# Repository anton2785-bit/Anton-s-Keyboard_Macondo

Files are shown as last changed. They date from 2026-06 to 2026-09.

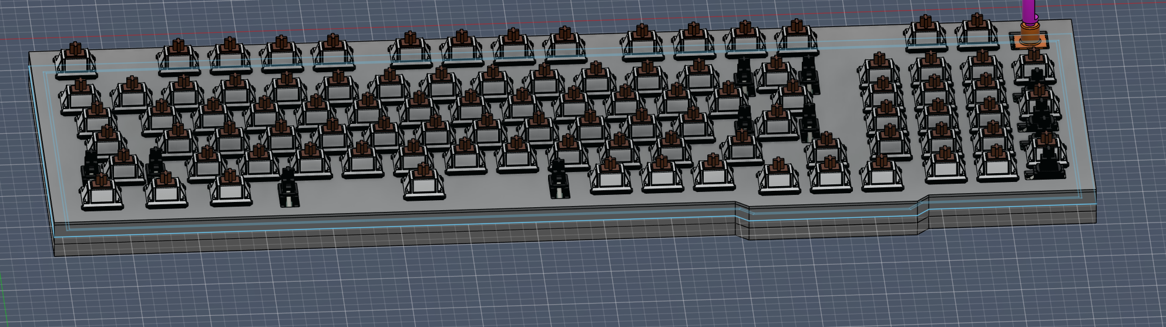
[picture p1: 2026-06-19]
Images/Assembly.png

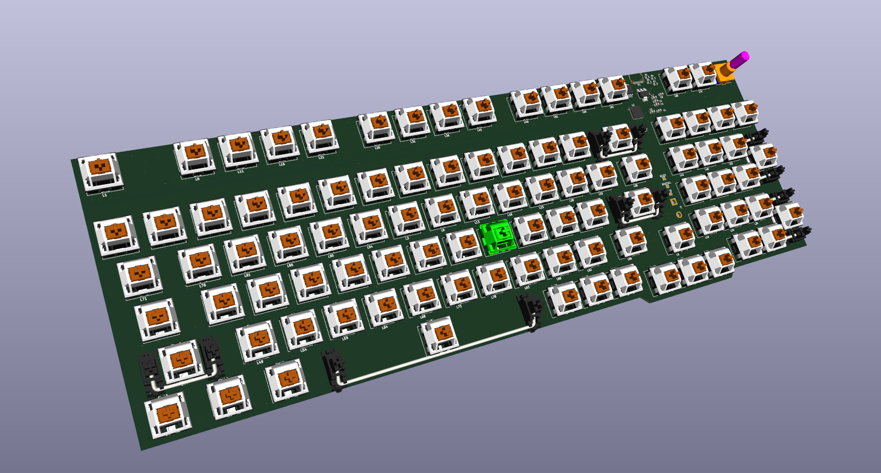
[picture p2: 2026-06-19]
Images/3d model PCB.png

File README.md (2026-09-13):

# Anton's kayboard
--- 
### What is this project
* This is a keyboar that uses thr 1800 compact layout (an almost 100% keyboard without most of the keys between the enter and the numpad). This keyboard uses an rp2040 chip for its 30 gpio pins that make the making of the keyboard PCB layout easier. Bellow every hotswapable key there is a LED that is wired to every other one and can be controlled with code. 
3d model PCB

--- 
### Why I made this project
* I made this keyboard because I wanted to try a bigger more complx PCB that I would be able to use everyday.
* Also I wanted to update my keyboard with one that I made.

--- 
### Images
* The schematic for the PCB
schematic
* The schematic for the hierarchal sheets and what is in it
Shematic herarcial sheets
* The layout and the PCB
PCB
* The 3D model of the case and assembly of the keyboard
* 
Assembly

--- 
### BOM
| Component | Purpose | Qty | Total Cost (USD) | Distributor |
|---|---|:---:|:---:|---|
| Gateron Stabilizer | Prevents larger switches from wobbling | 1 | $9.45 | Gateron |
| Decoupling Capacitors (100nF) | Reduce electrical noise before the LEDs | 2 | $3.20 | AliExpress |
| LEDs (SK6812 Mini-E) | RGB underglow beneath the switches | 1 | $3.56 | AliExpress |
| Keycaps | Keycaps | 1 | $15.78 | AliExpress |
| Rotary Encoder (EC11E) | Rotary knob for volume / scroll | 1 | $2.78 | AliExpress |
| Diodes (1N4148W) | Prevent signal backflow in the matrix | 2 | $3.60 | AliExpress |
| Resistors (4.7 kΩ and 350 Ω) | Current limiting for LEDs and I²C pull-ups | 1 | $4.10 | AliExpress |
| Foam | Sound dampening layer under the PCB | 1 | $7.77 | AliExpress |
| Coiled Cable | Connecting cable for the keyboard | 1 | $5.55 | AliExpress |
| PCB | Main circuit board | 1 | $59.00 | JLCPCB |
| Microcontroller (YD-RP2040) | Runs the keyboard firmware (KMK / CircuitPython) | 1 | $2.94 | AliExpress |
| Gateron Switches | The switches you type on | 1 | $29.00 | Gateron |
| Hotswap Sockets | Allow switches to be swapped without soldering | 1 | $6.68 | Gateron |
| **Total** | | | **$153.51** | |

--- 
### Assembly
* First you need to soulder the smaller components (the diodes and capacitors) just for your sanity because later it will get harder.
* The secpnd smallest thingyou need to soulder many of are the LEDs.
* After that you are free to soulder the hotswap sockets.
* The chip can be souldered at any time.
* The keys and kaycaps must be placed after the PCB is put into the case and secured with the top case.

--- 
### Known problems
* The code is almost entirely made by claude because I dont have the chip with me and I cant write the code.

--- 
### Credits
* Designed and built by *(Anton/ Anton-2785-bit)
* Inspired by open‑source mechanical keyboard and hackpad communities (https://forge.hackclub.com/).

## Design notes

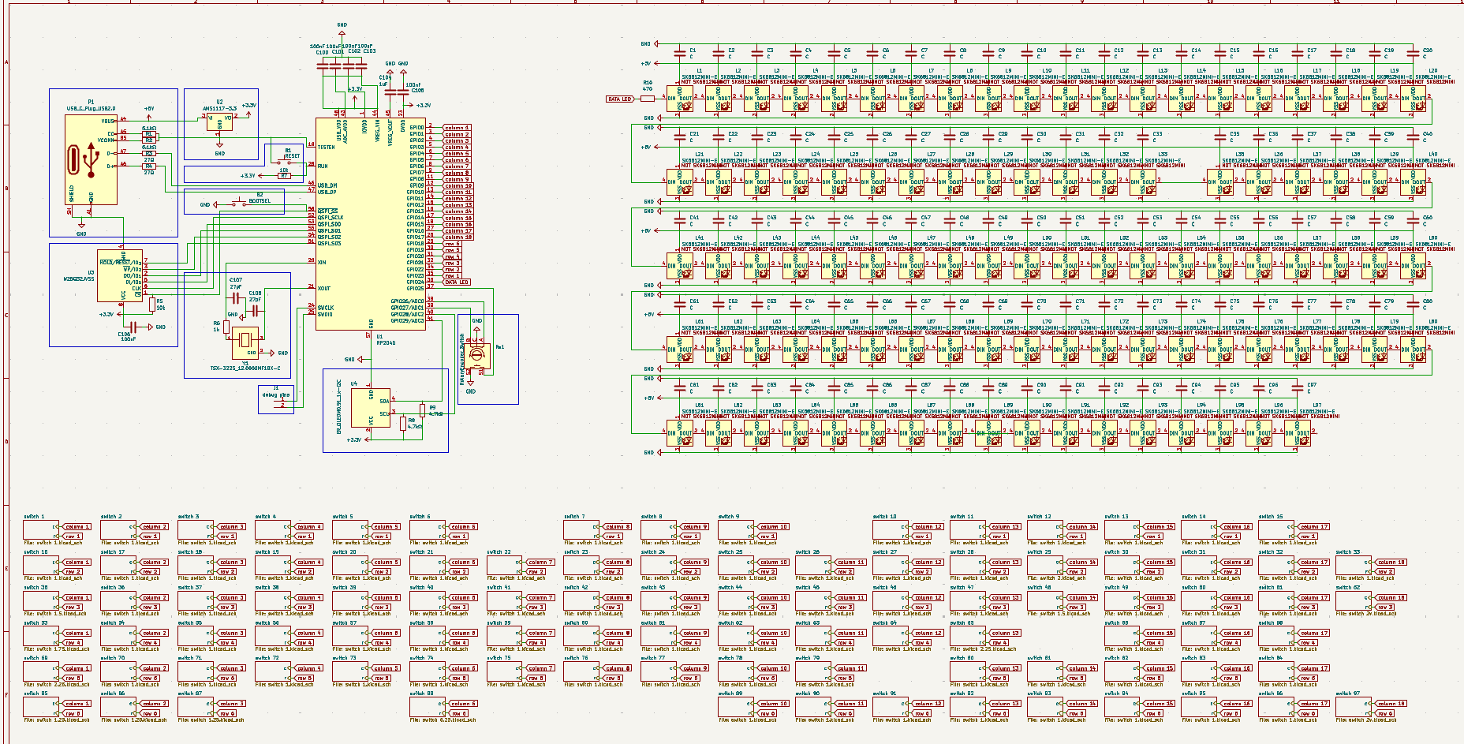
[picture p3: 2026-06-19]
Images/schematic.png

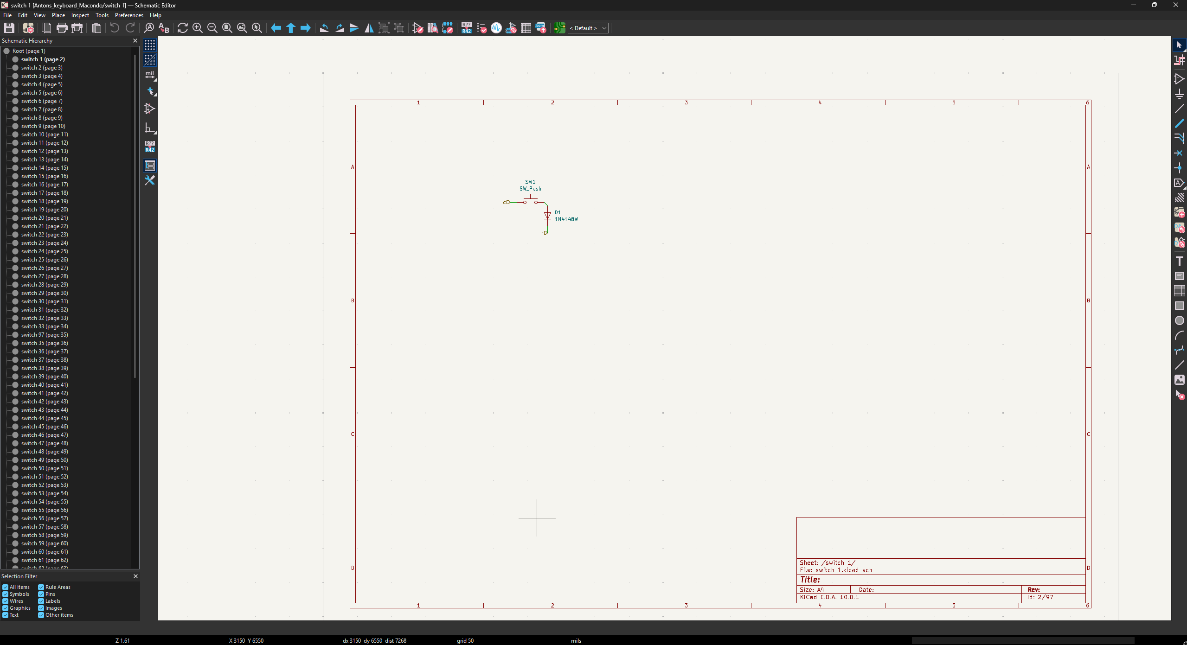
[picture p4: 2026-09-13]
Images/Shematic herarcial sheets.png

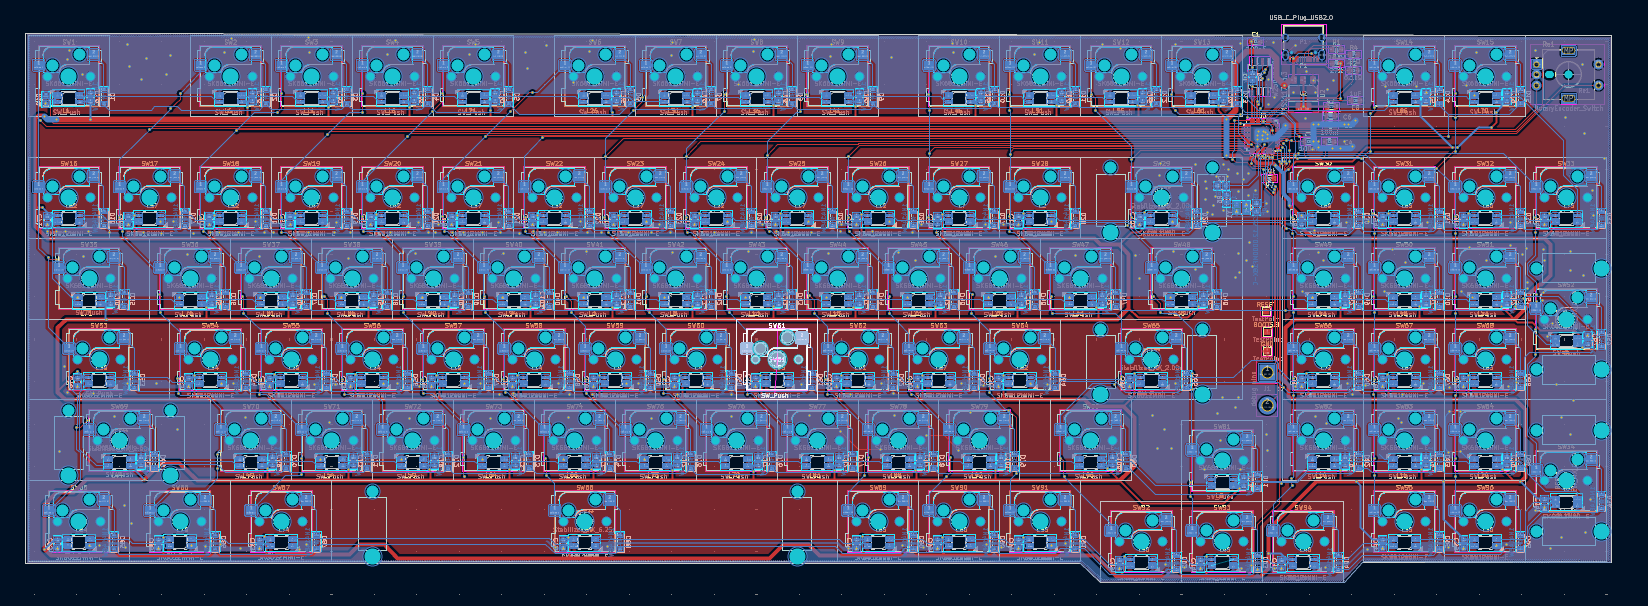
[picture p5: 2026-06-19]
Images/PCB.png

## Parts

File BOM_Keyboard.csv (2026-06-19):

Name | Purpose | Quantity | Total Cost (USD) | Link | Distributor
Gateroon stabilizer | makes the bigger switches not wable | 1 | 9.45 |  | gateron
decoupling capacitors ( 100nF ) | The capacitors are for lowering the electrical noise before the LEDs | 2 | 3.20 |  | Aliexpress
LEDs (SK 6812 mini E) | The LEDs bellow the switches | 1 | 3.56 |  | Aliexpress
keycaps | Keycaps | 1 | 15.78 |  | Aliexpress
Rotary encoder ( EC11E ) | A knob for twisting | 1 | 2.78 |  | Aliexpress
Diodes ( 1N4148W ) | Diodes, that stop form signal going back | 2 | 3.60 |  | Aliexpress
Resistors ( Pack of many ) | Resistors ( 4.7 kΩ and 350Ω) | 1 | 4.10 |  | Aliexpress
Foam | Used for making the keyboard sound betetr, its placed bellow the PCB | 1 | 7.77 |  | Aliexpress
Cable for keyboard | A cool coiled cable for the cable | 1 | 5.55 |  | Aliexpress
PCB | PCB | 1 | 59.00 |  | JLCPCB
Microcontroller (YD-RP 2040) | The microcontroller for the keyboard | 1 | 2.94 |  | Aliexpress
Gateroon switches | These are the switches that you type on | 1 | 29.00 |  | Gateron
Hotswap module | These modules allow for the easy change of the switches | 1 | 6.68 |  | Gateron

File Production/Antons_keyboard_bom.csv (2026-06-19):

Designator | Footprint | Quantity | Value | LCSC Part #
BOOTSEL, GND, RESET | TestPoint_Pad_1.5x1.5mm | 3 | TestPoint
C1, C4, C5, C6, C7, C9 | 0805 | 6 | 100nF
C10, C100, C101, C102, C103, C104, C105, C11, C12, C13, C14, C15, C16, C17, C18, C19, C20, C21, C22, C23, C24, C25, C26, C27, C28, C29, C30, C31, C32, C33, C34, C35, C36, C37, C38, C39, C40, C41, C42, C43, C44, C45, C46, C47, C48, C49, C50, C51, C52, C53, C54, C55, C56, C57, C58, C59, C60, C61, C62, C63, C64, C65, C66, C67, C68, C69, C70, C71, C72, C73, C74, C75, C76, C77, C78, C79, C80, C81, C82, C83, C84, C85, C86, C87, C88, C89, C90, C91, C92, C93, C94, C95, C96, C97, C98, C99 | 0805 | 96 | C
C2, C3 | 0805 | 2 | 27pF
C8 | 0805 | 1 | 1uF
D1, D10, D11, D12, D13, D14, D15, D16, D17, D18, D19, D2, D20, D21, D22, D23, D24, D25, D26, D27, D28, D29, D3, D30, D31, D32, D33, D34, D35, D36, D37, D38, D39, D4, D40, D41, D42, D43, D44, D45, D46, D47, D48, D49, D5, D50, D51, D52, D53, D54, D55, D56, D57, D58, D59, D6, D60, D61, D62, D63, D64, D65, D66, D67, D68, D69, D7, D70, D71, D72, D73, D74, D75, D76, D77, D78, D79, D8, D80, D81, D82, D83, D84, D85, D86, D87, D88, D89, D9, D90, D91, D92, D93, D94, D95, D96 | D_SOD-123 | 96 | 1N4148W
J1 | SolderWire-2sqmm_1x02_P7.8mm_D2mm_OD3.9mm | 1 | debug pins
L1, L10, L11, L12, L13, L14, L15, L16, L17, L18, L19, L2, L20, L21, L22, L23, L24, L25, L26, L27, L28, L29, L3, L30, L31, L32, L33, L34, L35, L36, L37, L38, L39, L4, L40, L41, L42, L43, L44, L45, L46, L47, L48, L49, L5, L50, L51, L52, L53, L54, L55, L56, L57, L58, L59, L6, L60, L61, L62, L63, L64, L65, L66, L67, L68, L69, L7, L70, L71, L72, L73, L74, L75, L76, L77, L78, L79, L8, L80, L81, L82, L83, L84, L85, L86, L87, L88, L89, L9, L90, L91, L92, L93, L94, L95, L96 | SK6812MINI-E_fixed | 96 | SK6812MINI-E
P1 | USB_C_Receptacle_HRO_TYPE-C-31-M-12 | 1 | USB_C_Plug_USB2.0
R1, R2 | 0805 | 2 | 5.1kΩ
R10 | 0805 | 1 | 470
R3, R4 | 0805 | 2 | 27Ω
R5, R7 | 0805 | 2 | 10k
R6 | 0805 | 1 | 1k
RE1 | RotaryEncoder_Alps_EC11E-Switch_Vertical_H20mm_MountingHoles | 1 | RotaryEncoder_Switch
SW1, SW10, SW11, SW12, SW13, SW14, SW15, SW16, SW17, SW18, SW19, SW2, SW20, SW21, SW22, SW23, SW24, SW25, SW26, SW27, SW28, SW3, SW30, SW31, SW32, SW33, SW36, SW37, SW38, SW39, SW4, SW40, SW41, SW42, SW43, SW44, SW45, SW46, SW47, SW49, SW5, SW50, SW51, SW54, SW55, SW56, SW57, SW58, SW59, SW6, SW60, SW61, SW62, SW63, SW64, SW66, SW67, SW68, SW7, SW70, SW71, SW72, SW73, SW74, SW75, SW76, SW77, SW78, SW79, SW8, SW80, SW81, SW82, SW83, SW84, SW89, SW9, SW90, SW91, SW92, SW93, SW94, SW95, SW96 | Hotswap_MX_1.00u | 84 | SW_Push
SW29 | Hotswap_MX_2.00u | 1 | SW_Push
SW34, SW52 | Hotswap_MX_2.00u_90deg | 2 | SW_Push
SW35, SW48 | Hotswap_MX_1.50u | 2 | SW_Push
SW53 | Hotswap_MX_1.75u | 1 | SW_Push
SW65, SW69 | Hotswap_MX_2.25u | 2 | SW_Push
SW85, SW86, SW87 | Hotswap_MX_1.25u | 3 | SW_Push
SW88 | Hotswap_MX_6.25u | 1 | SW_Push
U1 | SOIC-8_5.3x5.3mm_P1.27mm | 1 | W25Q32JVSS
U2 | SOT-223-3_TabPin2 | 1 | AMS1117-3.3
U3 | QFN-56-1EP_7x7mm_P0.4mm_EP3.2x3.2mm | 1 | RP2040
Y1 | XTAL_TSX-3225_24.0000MF18X-C | 1 | TSX-3225_12.0000MF18X-C

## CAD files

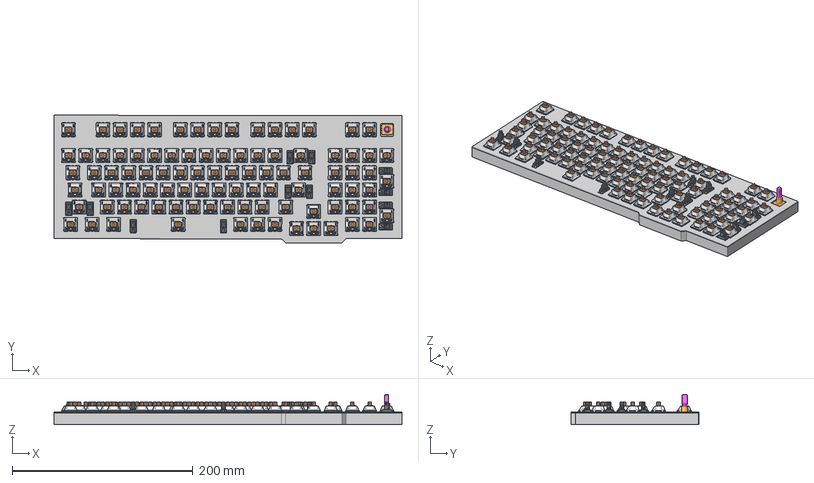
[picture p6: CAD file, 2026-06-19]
CAD/Antons_keyboard.step
385.3 x 141.4 x 33.5 mm
Hotswap_MX x 96
MX_PCB x 96
Stabilizer_MX_2.00u x 10
SK6812-E--3DModel-STEP-418109 x 96
ec11e18244a5
R_0805_2012Metric x 8
C_0805_2012Metric x 105
Stabilizer_MX_6.25u
SOT-223
SOIC-8_5.3x5.3mm_P1.27mm
QFN-56-1EP_7x7mm_P0.4mm_EP3.2x3.2mm
D_SOD-123 x 96
Antons_keyboard_Macondo_PCB

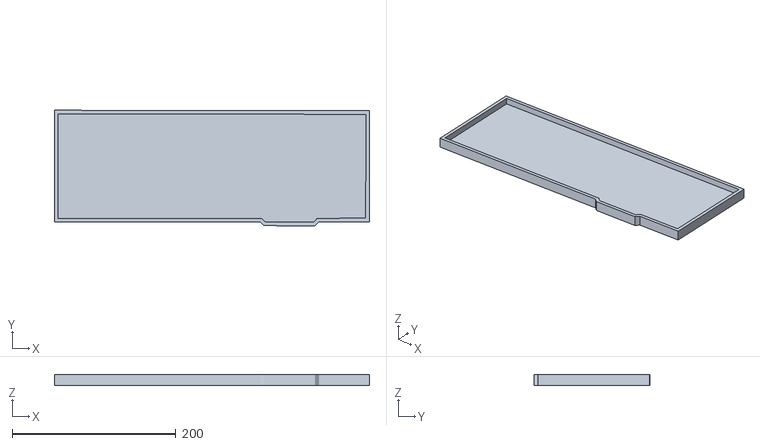
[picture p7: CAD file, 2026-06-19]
Production/Bottom case keyboard.stl
385.3 x 141.4 x 13.0

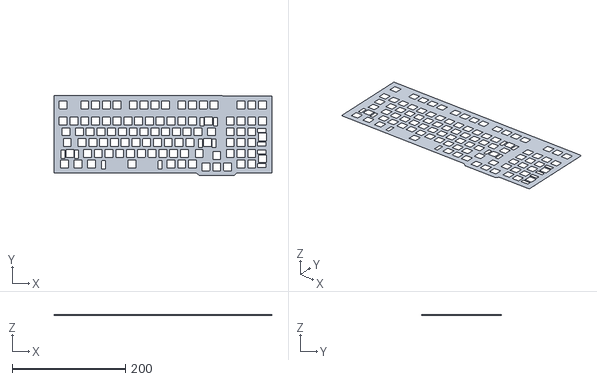
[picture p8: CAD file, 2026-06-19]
Production/top plate keyboard.stl
385.3 x 141.4 x 1.00

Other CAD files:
CAD/Antons_keyboard.f3d

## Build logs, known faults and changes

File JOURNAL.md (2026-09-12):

---
title: "Keyboard"
author: "antondimitrov2785"
description: "Its a keyboard using the 1800 compact layout"
created_at: "2026-09-11"
---

# 2026-09-11: Making the case

**Total time spent: 1.0 hours**

I didnt make it complicated. tye top plate will just slide in befort any of the keys are placed and then they will secure the plate down 

# 2026-09-11: Adding GND and 3D models

**Total time spent: 2.5 hours**

In this time I had to add like 150 vias all around the PCB because I had screwed up with one of the steps that were made to make the process easier. Other than that it is all good. 
After that I had to find a way to add the 3D models. I had forgotten how t o do that but I managed to do it and now everything but the keycaps is there (I think there is no need of them on the switches and they will make the process a bt harder).

# 2026-09-11: conected the LEDs to the 5v rails

**Total time spent: 1.5 hours**

It wasnt ahrd. My the only thing that I didnt account for was the many vias that I needed to place. I had specificly wanted to make it easy to wire then the GND, but it looks like it wouldnt happen


# 2026-09-11: Adding stabilizers and 5v rail

**Total time spent: 2.5 hours**

I needed the 5v rail for all of the LEDs. That is why it is much ticker than the other lines. The stabilizers were straight forward. 


# 2026-09-11: Connecting some resistors and lines

**Total time spent: 0.5 hours**

I had forgotten to add some of the resistors that are connected to the USB and chip. I moved the crystal which I will wire some other day. 


# 2026-09-11: making the columns bus

**Total time spent: 1.5 hours**

I needed to connect every column to the chip. And I didnt want to make it too hard later on with the GND layers. 


# 2026-09-11: Making the chip assembly

**Total time spent: 1.0 hours**

I needed to add the chip modules and all of the caps and everything that is related to it. Now I haave to connect every column and row.


# 2026-09-11: Adding LED and caps

**Total time spent: 3.0 hours**

I needed to add every led and capacitor. FOr each other row I had to flip the LED and the cap so that it would be easier to wire it later. that alone will save me 2 hours in the future. 

# 2026-09-11: Arranging the Switches

**Total time spent: 4.0 hours**

I added the footrpints and I needed to start to arrangе all of the switches and LEDs. 

After the hours I spent arranging the switches and diodes I have it for now. I spent more time than I needed because I wanted all of them to be at the same place relative to the centre of the switch to make it easier to wire and soulder later.  


# 2026-09-11: Assigning footprints

**Total time spent: 1.0 hours**

I wanted to handsoulder everything do I made the caps size 0805 to make it easier and the diodes are sot-123. The switches will be on hotswap module. 


# 2026-09-11: Adding LEDs and caps

**Total time spent: 1.0 hours**

Almost each LED needs an capacitor to smooth out the current for each LED. This is required because there are 96 LED on one single 5v line. 


# 2026-09-11: Adding the switches

**Total time spent: 2.0 hours**

I decided to place each key into its own sheet so it would be easier to assign the footprints later. The last thing I need to add to the schematic is the LED with their caps and then Im going to start on the layout and PCB. 


# 2026-09-11: The chip side is done

**Total time spent: 2.0 hours**

This part wasnt the easiest nor of the hardest. I just had to search what pin to connect where. And now I have to make the LEDs and the switches. 


# 2026-09-11: Getting schematic symbols

**Total time spent: 1.0 hours**

This is the symbols that will be for the chip and the things around it. The keys and diodes will follow up next. 


# 2026-09-11: Chip

**Total time spent: 1.0 hours**

For this keyboard I have decided to not use a devboard. I will integrate the chip with all of the components it needs into the keyboard to make the keyboard a bit smaller and easier to work with. 

# 2026-09-11: Layout

**Total time spent: 1.5 hours**

I will use a 1800 compact layout. I have chosen this one because I dont need the keys that are cut short from the full sized keyboard and if I happen to need them they will be just on a lower layer of the symbols.

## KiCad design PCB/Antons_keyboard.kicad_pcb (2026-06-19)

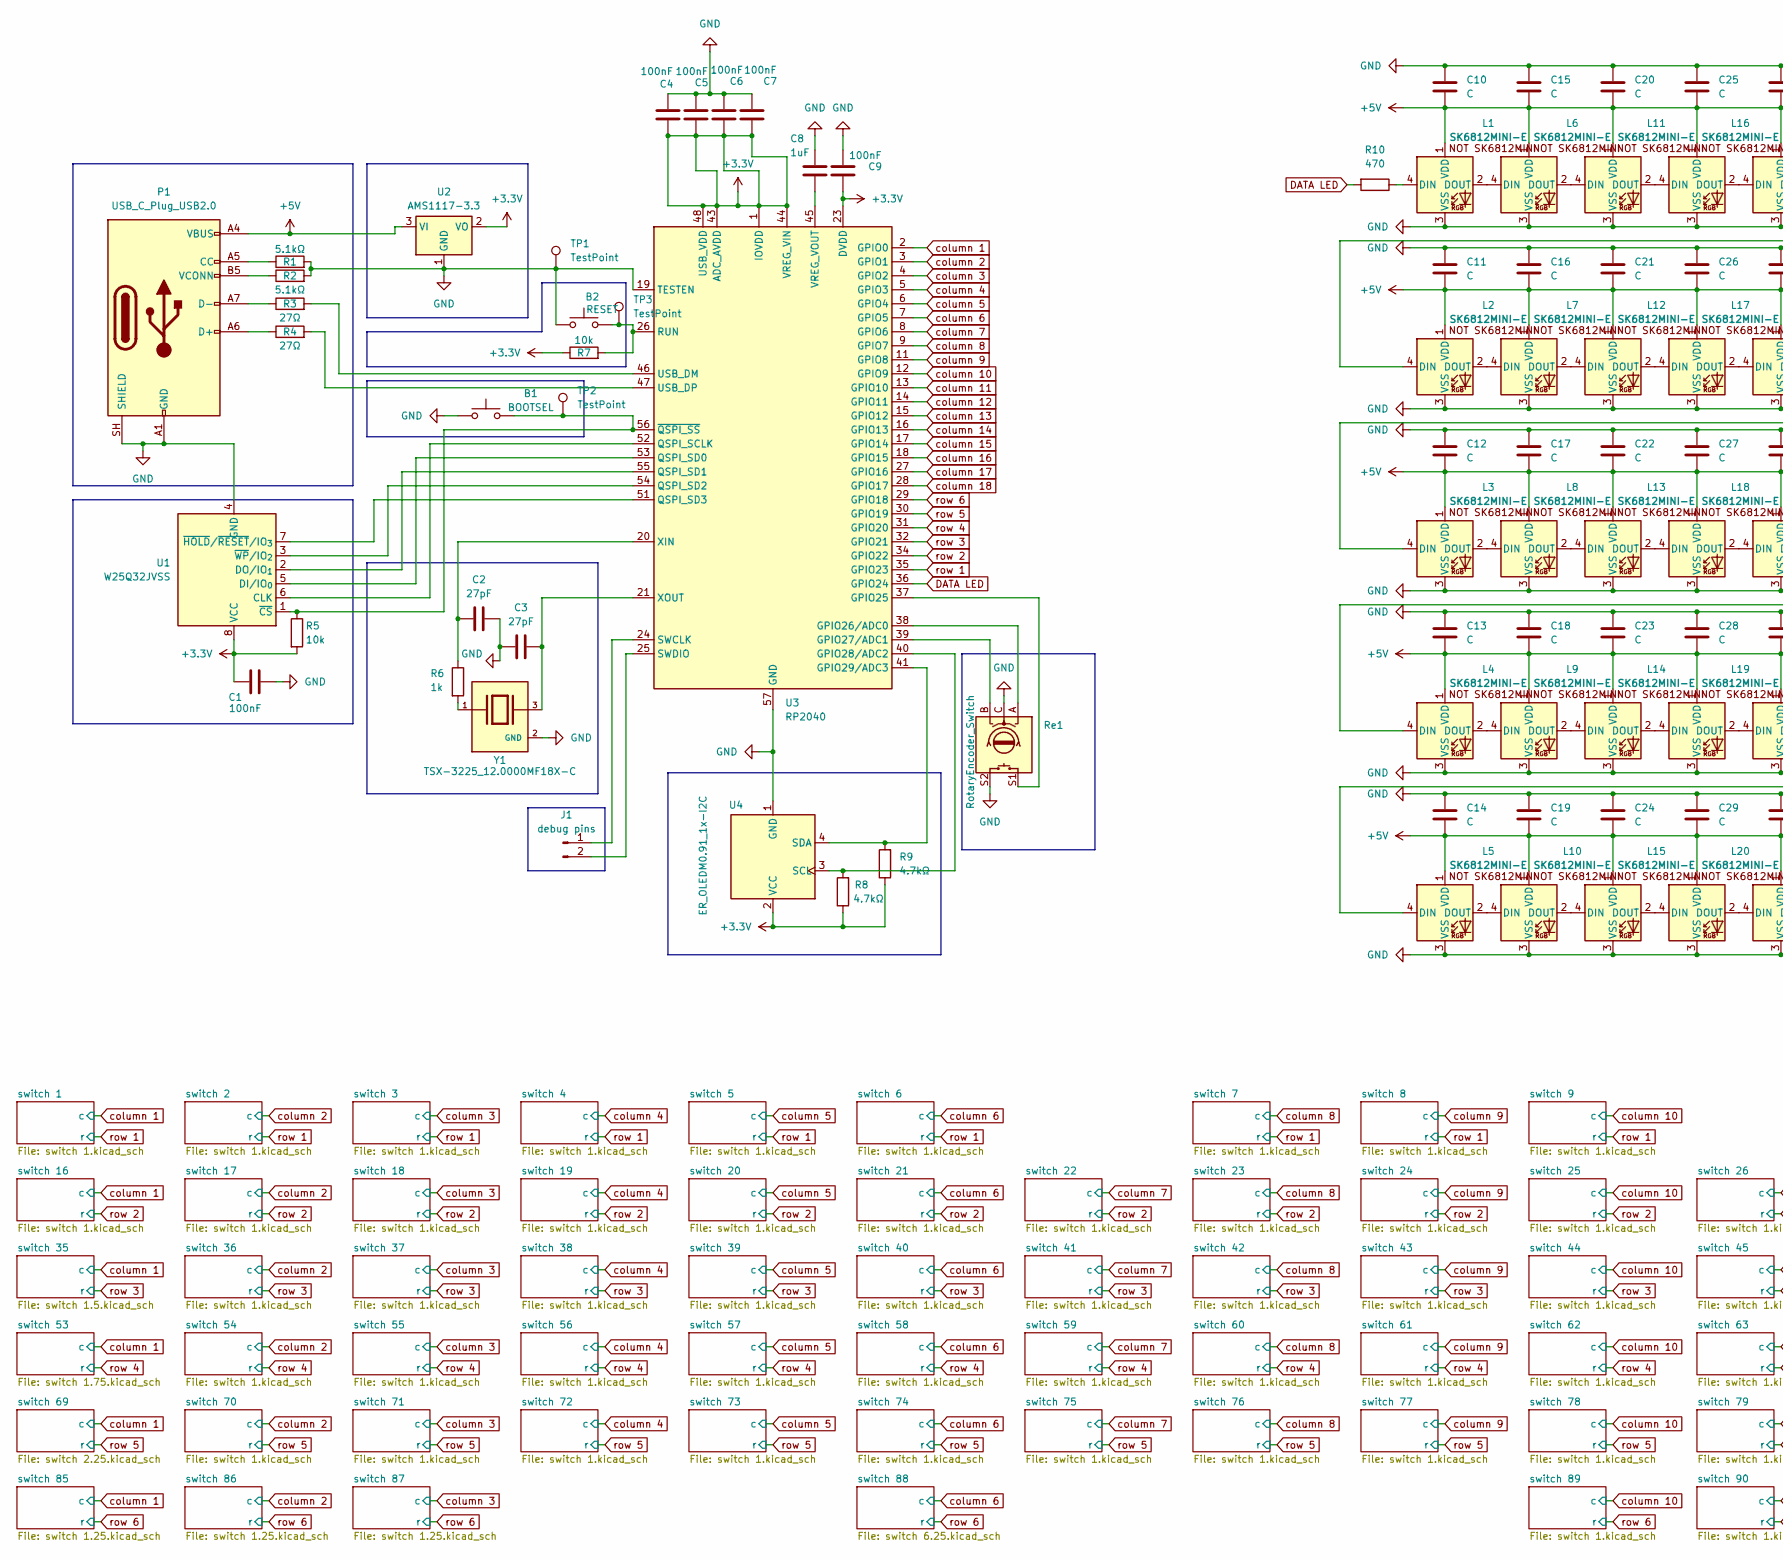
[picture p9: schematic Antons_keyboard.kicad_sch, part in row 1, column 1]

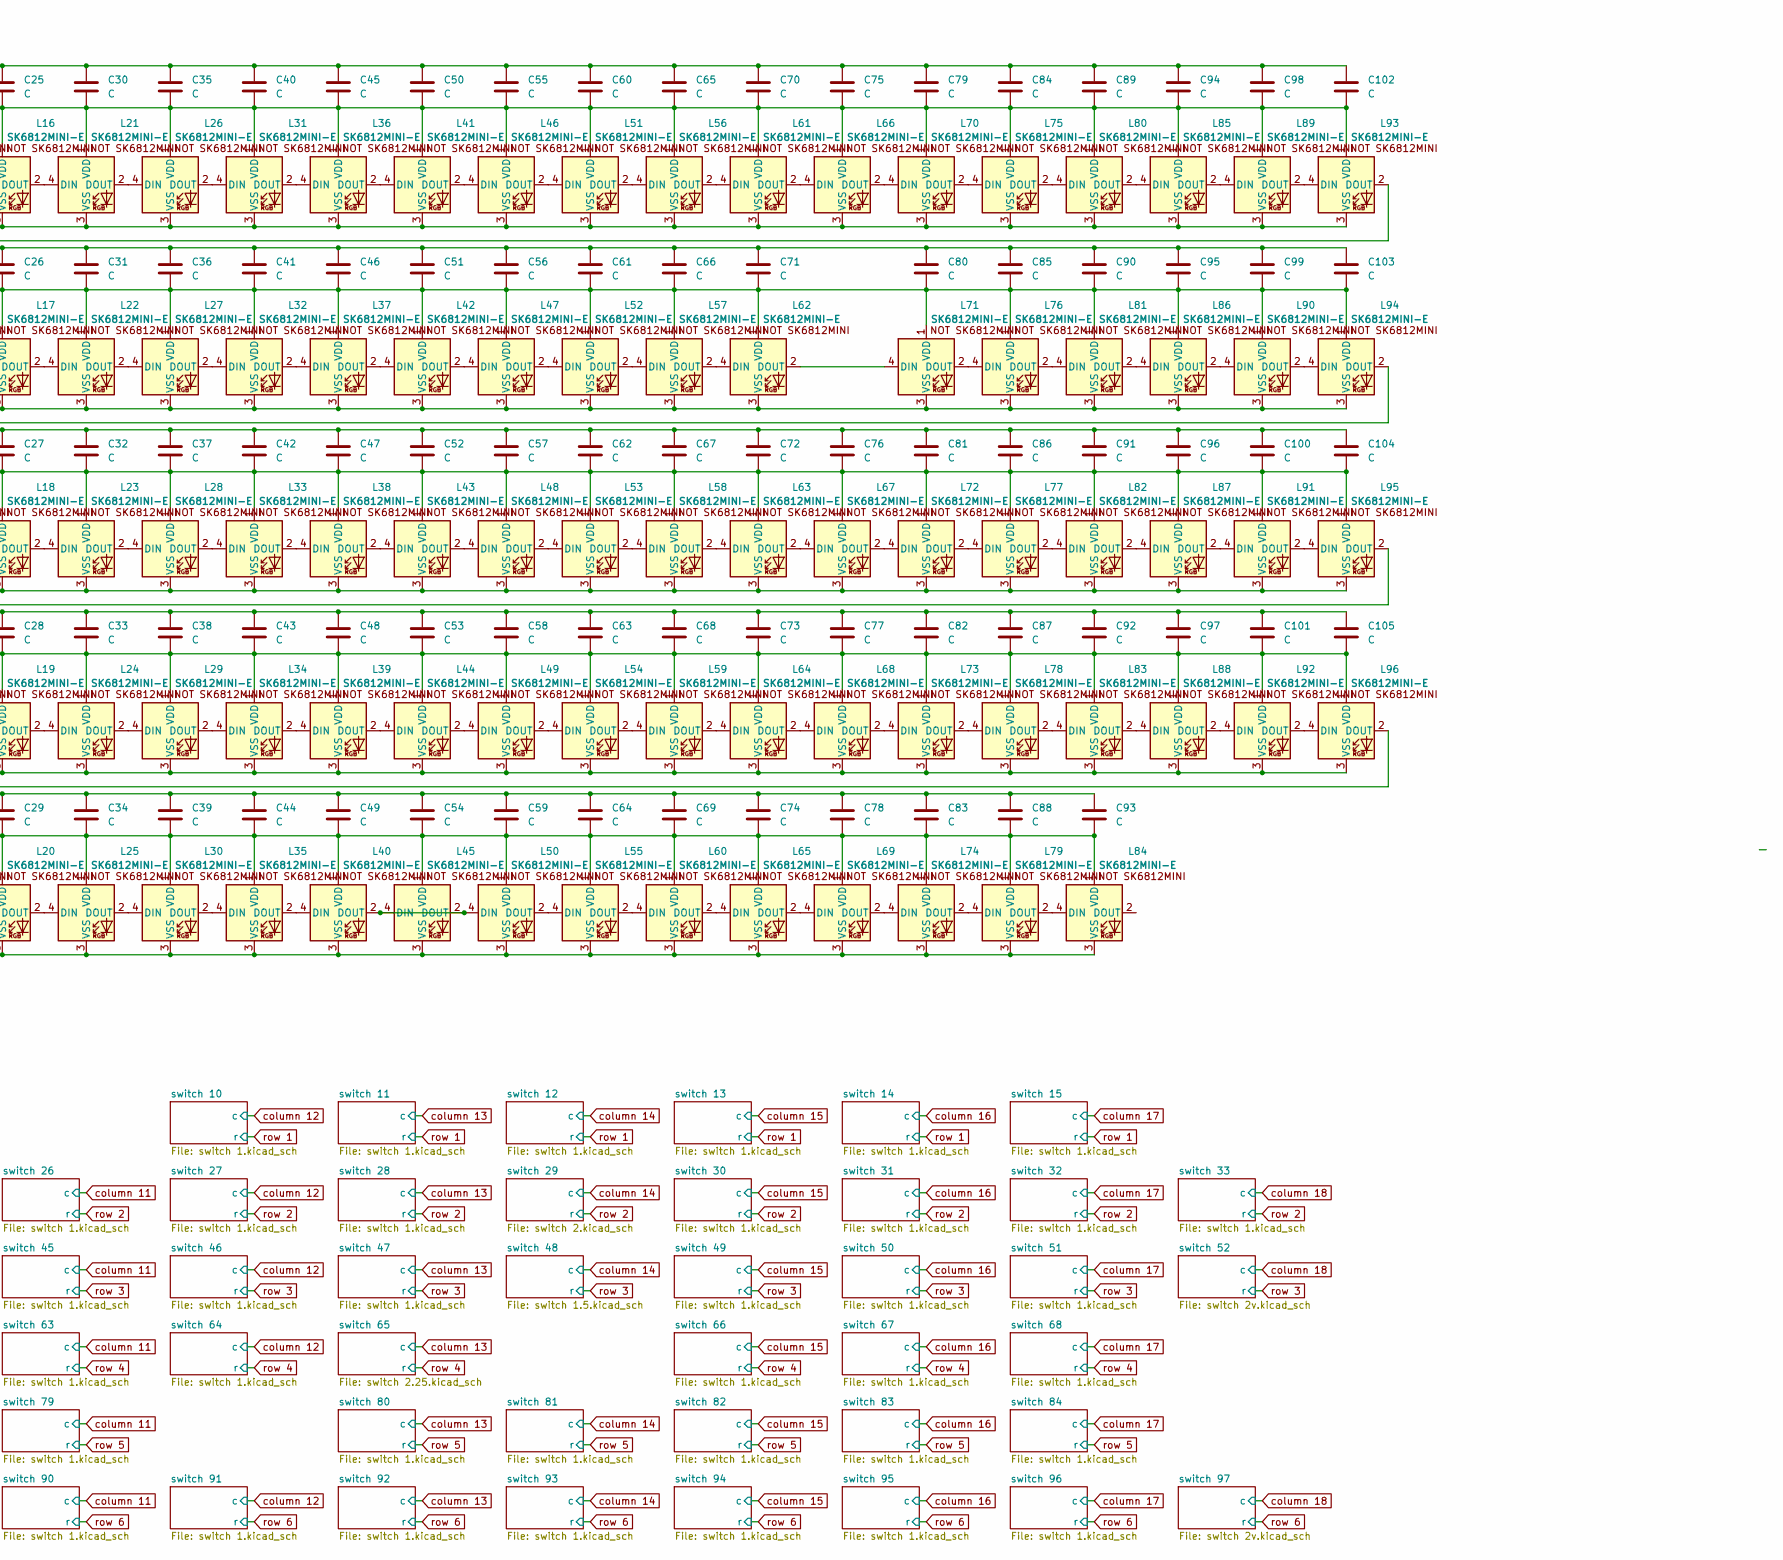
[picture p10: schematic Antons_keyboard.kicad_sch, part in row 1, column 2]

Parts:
B1: BOOTSEL
B2: RESET
C1, C4, C5, C6, C7, C9: 100nF; C_0805_2012Metric_Pad1.18x1.45mm_HandSolder
C2, C3: 27pF; C_0805_2012Metric_Pad1.18x1.45mm_HandSolder
C8: 1uF; C_0805_2012Metric_Pad1.18x1.45mm_HandSolder
C10, C11, C12, C13, C14, C15, C16, C17, C18, C19, C20, C21, C22, C23, C24, C25, C26, C27, C28, C29, C30, C31, C32, C33, C34, C35, C36, C37, C38, C39, C40, C41, C42, C43, C44, C45, C46, C47, C48, C49, C50, C51, C52, C53, C54, C55, C56, C57, C58, C59, C60, C61, C62, C63, C64, C65, C66, C67, C68, C69, C70, C71, C72, C73, C74, C75, C76, C77, C78, C79, C80, C81, C82, C83, C84, C85, C86, C87, C88, C89, C90, C91, C92, C93, C94, C95, C96, C97, C98, C99, C100, C101, C102, C103, C104, C105: C; C_0805_2012Metric_Pad1.18x1.45mm_HandSolder
J1: debug pins; SolderWire-2sqmm_1x02_P7.8mm_D2mm_OD3.9mm
L1, L2, L3, L4, L5, L6, L7, L8, L9, L10, L11, L12, L13, L14, L15, L16, L17, L18, L19, L20, L21, L22, L23, L24, L25, L26, L27, L28, L29, L30, L31, L32, L33, L34, L35, L36, L37, L38, L39, L40, L41, L42, L43, L44, L45, L46, L47, L48, L49, L50, L51, L52, L53, L54, L55, L56, L57, L58, L59, L60, L61, L62, L63, L64, L65, L66, L67, L68, L69, L70, L71, L72, L73, L74, L75, L76, L77, L78, L79, L80, L81, L82, L83, L84, L85, L86, L87, L88, L89, L90, L91, L92, L93, L94, L95, L96: SK6812MINI-E; SK6812MINI-E_fixed
P1: USB_C_Plug_USB2.0; USB_C_Receptacle_HRO_TYPE-C-31-M-12
R1, R2: 5.1kΩ; R_0805_2012Metric_Pad1.20x1.40mm_HandSolder
R3, R4: 27Ω; R_0805_2012Metric_Pad1.20x1.40mm_HandSolder
R5, R7: 10k; R_0805_2012Metric_Pad1.20x1.40mm_HandSolder
R6: 1k; R_0805_2012Metric_Pad1.20x1.40mm_HandSolder
R8, R9: 4.7kΩ; R_0805_2012Metric_Pad1.20x1.40mm_HandSolder
R10: 470; R_0805_2012Metric_Pad1.20x1.40mm_HandSolder
Re1: RotaryEncoder_Switch; RotaryEncoder_Alps_EC11E-Switch_Vertical_H20mm_MountingHoles
TP1, TP2, TP3: TestPoint; TestPoint_Pad_1.5x1.5mm
U1: W25Q32JVSS; SOIC-8_5.3x5.3mm_P1.27mm
U2: AMS1117-3.3; SOT-223-3_TabPin2
U3: RP2040; QFN-56-1EP_7x7mm_P0.4mm_EP3.2x3.2mm
U4: ER_OLEDM0.91_1x-I2C
Y1: TSX-3225_12.0000MF18X-C; XTAL_TSX-3225_24.0000MF18X-C; PARTREV N/A

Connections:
+3.3V: C1.1, C4.1, C5.1, C6.1, C7.1, C9.1, R5.2, R7.1, R8.1, R9.1, U1.8 (VCC), U2.2 (VO), U3.1 (IOVDD), U3.10 (IOVDD), U3.22 (IOVDD), U3.23 (DVDD), U3.33 (IOVDD), U3.42 (IOVDD), U3.43 (ADC_AVDD), U3.44 (VREG_VIN), U3.48 (USB_VDD), U3.49 (IOVDD), U3.50 (DVDD), U4.2 (VCC)
+5V: C10.1, C11.1, C12.1, C13.1, C14.1, C15.1, C16.1, C17.1, C18.1, C19.1, C20.1, C21.1, C22.1, C23.1, C24.1, C25.1, C26.1, C27.1, C28.1, C29.1, C30.1, C31.1, C32.1, C33.1, C34.1, C35.1, C36.1, C37.1, C38.1, C39.1, C40.1, C41.1, C42.1, C43.1, C44.1, C45.1, C46.1, C47.1, C48.1, C49.1, C50.1, C51.1, C52.1, C53.1, C54.1, C55.1, C56.1, C57.1, C58.1, C59.1, C60.1, C61.1, C62.1, C63.1, C64.1, C65.1, C66.1, C67.1, C68.1, C69.1, C70.1, C71.1, C72.1, C73.1, C74.1, C75.1, C76.1, C77.1, C78.1, C79.1, C80.1, C81.1, C82.1, C83.1, C84.1, C85.1, C86.1, C87.1, C88.1, C89.1, C90.1, C91.1, C92.1, C93.1, C94.1, C95.1, C96.1, C97.1, C98.1, C99.1, C100.1, C101.1, C102.1, C103.1, C104.1, C105.1, L1.1 (VDD), L2.1 (VDD), L3.1 (VDD), L4.1 (VDD), L5.1 (VDD), L6.1 (VDD), L7.1 (VDD), L8.1 (VDD), L9.1 (VDD), L10.1 (VDD), L11.1 (VDD), L12.1 (VDD), L13.1 (VDD), L14.1 (VDD), L15.1 (VDD), L16.1 (VDD), L17.1 (VDD), L18.1 (VDD), L19.1 (VDD), L20.1 (VDD), L21.1 (VDD), L22.1 (VDD), L23.1 (VDD), L24.1 (VDD), L25.1 (VDD), L26.1 (VDD), L27.1 (VDD), L28.1 (VDD), L29.1 (VDD), L30.1 (VDD), L31.1 (VDD), L32.1 (VDD), L33.1 (VDD), L34.1 (VDD), L35.1 (VDD), L36.1 (VDD), L37.1 (VDD), L38.1 (VDD), L39.1 (VDD), L40.1 (VDD), L41.1 (VDD), L42.1 (VDD), L43.1 (VDD), L44.1 (VDD), L45.1 (VDD), L46.1 (VDD), L47.1 (VDD), L48.1 (VDD), L49.1 (VDD), L50.1 (VDD), L51.1 (VDD), L52.1 (VDD), L53.1 (VDD), L54.1 (VDD), L55.1 (VDD), L56.1 (VDD), L57.1 (VDD), L58.1 (VDD), L59.1 (VDD), L60.1 (VDD), L61.1 (VDD), L62.1 (VDD), L63.1 (VDD), L64.1 (VDD), L65.1 (VDD), L66.1 (VDD), L67.1 (VDD), L68.1 (VDD), L69.1 (VDD), L70.1 (VDD), L71.1 (VDD), L72.1 (VDD), L73.1 (VDD), L74.1 (VDD), L75.1 (VDD), L76.1 (VDD), L77.1 (VDD), L78.1 (VDD), L79.1 (VDD), L80.1 (VDD), L81.1 (VDD), L82.1 (VDD), L83.1 (VDD), L84.1 (VDD), L85.1 (VDD), L86.1 (VDD), L87.1 (VDD), L88.1 (VDD), L89.1 (VDD), L90.1 (VDD), L91.1 (VDD), L92.1 (VDD), L93.1 (VDD), L94.1 (VDD), L95.1 (VDD), L96.1 (VDD), P1.A4 (VBUS), P1.A9 (VBUS), P1.B4 (VBUS), P1.B9 (VBUS), U2.3 (VI)
DATA LED: R10.2, U3.36 (GPIO24)
GND: B1.1, B2.1, C1.2, C2.2, C3.1, C4.2, C5.2, C6.2, C7.2, C8.1, C9.2, C10.2, C11.2, C12.2, C13.2, C14.2, C15.2, C16.2, C17.2, C18.2, C19.2, C20.2, C21.2, C22.2, C23.2, C24.2, C25.2, C26.2, C27.2, C28.2, C29.2, C30.2, C31.2, C32.2, C33.2, C34.2, C35.2, C36.2, C37.2, C38.2, C39.2, C40.2, C41.2, C42.2, C43.2, C44.2, C45.2, C46.2, C47.2, C48.2, C49.2, C50.2, C51.2, C52.2, C53.2, C54.2, C55.2, C56.2, C57.2, C58.2, C59.2, C60.2, C61.2, C62.2, C63.2, C64.2, C65.2, C66.2, C67.2, C68.2, C69.2, C70.2, C71.2, C72.2, C73.2, C74.2, C75.2, C76.2, C77.2, C78.2, C79.2, C80.2, C81.2, C82.2, C83.2, C84.2, C85.2, C86.2, C87.2, C88.2, C89.2, C90.2, C91.2, C92.2, C93.2, C94.2, C95.2, C96.2, C97.2, C98.2, C99.2, C100.2, C101.2, C102.2, C103.2, C104.2, C105.2, L1.3 (VSS), L2.3 (VSS), L3.3 (VSS), L4.3 (VSS), L5.3 (VSS), L6.3 (VSS), L7.3 (VSS), L8.3 (VSS), L9.3 (VSS), L10.3 (VSS), L11.3 (VSS), L12.3 (VSS), L13.3 (VSS), L14.3 (VSS), L15.3 (VSS), L16.3 (VSS), L17.3 (VSS), L18.3 (VSS), L19.3 (VSS), L20.3 (VSS), L21.3 (VSS), L22.3 (VSS), L23.3 (VSS), L24.3 (VSS), L25.3 (VSS), L26.3 (VSS), L27.3 (VSS), L28.3 (VSS), L29.3 (VSS), L30.3 (VSS), L31.3 (VSS), L32.3 (VSS), L33.3 (VSS), L34.3 (VSS), L35.3 (VSS), L36.3 (VSS), L37.3 (VSS), L38.3 (VSS), L39.3 (VSS), L40.3 (VSS), L41.3 (VSS), L42.3 (VSS), L43.3 (VSS), L44.3 (VSS), L45.3 (VSS), L46.3 (VSS), L47.3 (VSS), L48.3 (VSS), L49.3 (VSS), L50.3 (VSS), L51.3 (VSS), L52.3 (VSS), L53.3 (VSS), L54.3 (VSS), L55.3 (VSS), L56.3 (VSS), L57.3 (VSS), L58.3 (VSS), L59.3 (VSS), L60.3 (VSS), L61.3 (VSS), L62.3 (VSS), L63.3 (VSS), L64.3 (VSS), L65.3 (VSS), L66.3 (VSS), L67.3 (VSS), L68.3 (VSS), L69.3 (VSS), L70.3 (VSS), L71.3 (VSS), L72.3 (VSS), L73.3 (VSS), L74.3 (VSS), L75.3 (VSS), L76.3 (VSS), L77.3 (VSS), L78.3 (VSS), L79.3 (VSS), L80.3 (VSS), L81.3 (VSS), L82.3 (VSS), L83.3 (VSS), L84.3 (VSS), L85.3 (VSS), L86.3 (VSS), L87.3 (VSS), L88.3 (VSS), L89.3 (VSS), L90.3 (VSS), L91.3 (VSS), L92.3 (VSS), L93.3 (VSS), L94.3 (VSS), L95.3 (VSS), L96.3 (VSS), P1.A1 (GND), P1.A12 (GND), P1.B1 (GND), P1.B12 (GND), P1.SH (SHIELD), R1.2, R2.2, Re1.C, Re1.S2, TP1.1, U1.4 (GND), U2.1 (GND), U3.19 (TESTEN), U3.57 (GND), U4.1 (GND), Y1.2 (GND), Y1.4 (GND); also elsewhere on the board
unnamed: J1.1, U3.24 (SWCLK)
unnamed: J1.2, U3.25 (SWDIO)
unnamed: L1.4 (DIN), R10.1
unnamed: L1.2 (DOUT), L6.4 (DIN)
unnamed: L2.4 (DIN), L93.2 (DOUT)
unnamed: L2.2 (DOUT), L7.4 (DIN)
unnamed: L3.4 (DIN), L94.2 (DOUT)
unnamed: L3.2 (DOUT), L8.4 (DIN)
unnamed: L4.4 (DIN), L95.2 (DOUT)
unnamed: L4.2 (DOUT), L9.4 (DIN)
unnamed: L5.4 (DIN), L96.2 (DOUT)
unnamed: L5.2 (DOUT), L10.4 (DIN)
unnamed: L10.2 (DOUT), L15.4 (DIN)
unnamed: L6.2 (DOUT), L11.4 (DIN)
unnamed: L11.2 (DOUT), L16.4 (DIN)
unnamed: L7.2 (DOUT), L12.4 (DIN)
unnamed: L12.2 (DOUT), L17.4 (DIN)
unnamed: L8.2 (DOUT), L13.4 (DIN)
unnamed: L13.2 (DOUT), L18.4 (DIN)
unnamed: L9.2 (DOUT), L14.4 (DIN)
unnamed: L14.2 (DOUT), L19.4 (DIN)
unnamed: L15.2 (DOUT), L20.4 (DIN)
unnamed: L16.2 (DOUT), L21.4 (DIN)
unnamed: L17.2 (DOUT), L22.4 (DIN)
unnamed: L18.2 (DOUT), L23.4 (DIN)
unnamed: L19.2 (DOUT), L24.4 (DIN)
unnamed: L20.2 (DOUT), L25.4 (DIN)
unnamed: L21.2 (DOUT), L26.4 (DIN)
unnamed: L22.2 (DOUT), L27.4 (DIN)
unnamed: L23.2 (DOUT), L28.4 (DIN)
unnamed: L24.2 (DOUT), L29.4 (DIN)
unnamed: L25.2 (DOUT), L30.4 (DIN)
unnamed: L26.2 (DOUT), L31.4 (DIN)
unnamed: L27.2 (DOUT), L32.4 (DIN)
unnamed: L28.2 (DOUT), L33.4 (DIN)
unnamed: L29.2 (DOUT), L34.4 (DIN)
unnamed: L30.2 (DOUT), L35.4 (DIN)
unnamed: L31.2 (DOUT), L36.4 (DIN)
unnamed: L32.2 (DOUT), L37.4 (DIN)
unnamed: L33.2 (DOUT), L38.4 (DIN)
unnamed: L34.2 (DOUT), L39.4 (DIN)
unnamed: L35.2 (DOUT), L40.4 (DIN)
unnamed: L36.2 (DOUT), L41.4 (DIN)
unnamed: L37.2 (DOUT), L42.4 (DIN)
unnamed: L38.2 (DOUT), L43.4 (DIN)
unnamed: L39.2 (DOUT), L44.4 (DIN)
unnamed: L40.2 (DOUT), L45.2 (DOUT), L45.4 (DIN), L50.4 (DIN)
unnamed: L41.2 (DOUT), L46.4 (DIN)
unnamed: L42.2 (DOUT), L47.4 (DIN)
unnamed: L43.2 (DOUT), L48.4 (DIN)
unnamed: L44.2 (DOUT), L49.4 (DIN)
unnamed: L46.2 (DOUT), L51.4 (DIN)
unnamed: L47.2 (DOUT), L52.4 (DIN)
unnamed: L48.2 (DOUT), L53.4 (DIN)
unnamed: L49.2 (DOUT), L54.4 (DIN)
unnamed: L50.2 (DOUT), L55.4 (DIN)
unnamed: L51.2 (DOUT), L56.4 (DIN)
unnamed: L52.2 (DOUT), L57.4 (DIN)
unnamed: L53.2 (DOUT), L58.4 (DIN)
unnamed: L54.2 (DOUT), L59.4 (DIN)
unnamed: L55.2 (DOUT), L60.4 (DIN)
unnamed: L56.2 (DOUT), L61.4 (DIN)
unnamed: L57.2 (DOUT), L62.4 (DIN)
unnamed: L58.2 (DOUT), L63.4 (DIN)
unnamed: L59.2 (DOUT), L64.4 (DIN)
unnamed: L60.2 (DOUT), L65.4 (DIN)
unnamed: L61.2 (DOUT), L66.4 (DIN)
unnamed: L62.2 (DOUT), L71.4 (DIN)
unnamed: L63.2 (DOUT), L67.4 (DIN)
unnamed: L64.2 (DOUT), L68.4 (DIN)
unnamed: L65.2 (DOUT), L69.4 (DIN)
unnamed: L66.2 (DOUT), L70.4 (DIN)
unnamed: L67.2 (DOUT), L72.4 (DIN)
unnamed: L68.2 (DOUT), L73.4 (DIN)
unnamed: L69.2 (DOUT), L74.4 (DIN)
unnamed: L70.2 (DOUT), L75.4 (DIN)
unnamed: L71.2 (DOUT), L76.4 (DIN)
unnamed: L72.2 (DOUT), L77.4 (DIN)
unnamed: L73.2 (DOUT), L78.4 (DIN)
unnamed: L74.2 (DOUT), L79.4 (DIN)
unnamed: L75.2 (DOUT), L80.4 (DIN)
unnamed: L76.2 (DOUT), L81.4 (DIN)
unnamed: L77.2 (DOUT), L82.4 (DIN)
unnamed: L78.2 (DOUT), L83.4 (DIN)
unnamed: L79.2 (DOUT), L84.4 (DIN)
unnamed: L80.2 (DOUT), L85.4 (DIN)
unnamed: L81.2 (DOUT), L86.4 (DIN)
unnamed: L82.2 (DOUT), L87.4 (DIN)
unnamed: L83.2 (DOUT), L88.4 (DIN)
unnamed: L85.2 (DOUT), L89.4 (DIN)
unnamed: L86.2 (DOUT), L90.4 (DIN)
unnamed: L87.2 (DOUT), L91.4 (DIN)
unnamed: L88.2 (DOUT), L92.4 (DIN)
unnamed: L89.2 (DOUT), L93.4 (DIN)
unnamed: L90.2 (DOUT), L94.4 (DIN)
unnamed: L91.2 (DOUT), L95.4 (DIN)
unnamed: L92.2 (DOUT), L96.4 (DIN)
unnamed: P1.A5 (CC), R1.1
unnamed: P1.A6 (D+), R4.1
unnamed: P1.A7 (D-), R3.1
unnamed: P1.B5 (VCONN), R2.1
unnamed: R6.2, Y1.1
unnamed: U1.6 (CLK), U3.52 (QSPI_SCLK)
unnamed: U1.5 (DI/IO_{0}), U3.53 (QSPI_SD0)
unnamed: U1.2 (DO/IO_{1}), U3.55 (QSPI_SD1)
unnamed 205: B1.2, R5.1, TP2.1, U1.1 (~CS), U3.56 (~QSPI_SS); also elsewhere on the board
unnamed: U1.7 (~HOLD/~RESET/IO_{3}), U3.51 (QSPI_SD3)
unnamed: U1.3 (~WP/IO_{2}), U3.54 (QSPI_SD2)
unnamed: Re1.S1, U3.37 (GPIO25)
unnamed: Re1.A, U3.38 (GPIO26/ADC0)
unnamed: Re1.B, U3.39 (GPIO27/ADC1)
unnamed: R8.2, U3.40 (GPIO28/ADC2), U4.3 (SCL)
unnamed: R9.2, U3.41 (GPIO29/ADC3), U4.4 (SDA)
unnamed 213: B2.2, R7.2, TP3.1, U3.26 (RUN); also elsewhere on the board
unnamed: R3.2, U3.46 (USB_DM)
unnamed: R4.2, U3.47 (USB_DP)
unnamed: C8.2, U3.45 (VREG_VOUT)
unnamed: C2.1, R6.1, U3.20 (XIN)
unnamed: C3.2, U3.21 (XOUT), Y1.3
column 1: U3.2 (GPIO0); also elsewhere on the board
column 2: U3.3 (GPIO1); also elsewhere on the board
column 3: U3.4 (GPIO2); also elsewhere on the board
column 4: U3.5 (GPIO3); also elsewhere on the board
column 5: U3.6 (GPIO4); also elsewhere on the board
column 6: U3.7 (GPIO5); also elsewhere on the board
column 7: U3.8 (GPIO6); also elsewhere on the board
column 8: U3.9 (GPIO7); also elsewhere on the board
column 9: U3.11 (GPIO8); also elsewhere on the board
column 10: U3.12 (GPIO9); also elsewhere on the board
column 11: U3.13 (GPIO10); also elsewhere on the board
column 12: U3.14 (GPIO11); also elsewhere on the board
column 13: U3.15 (GPIO12); also elsewhere on the board
column 14: U3.16 (GPIO13); also elsewhere on the board
column 15: U3.17 (GPIO14); also elsewhere on the board
column 16: U3.18 (GPIO15); also elsewhere on the board
column 17: U3.27 (GPIO16); also elsewhere on the board
column 18: U3.28 (GPIO17); also elsewhere on the board
row 1: U3.35 (GPIO23); also elsewhere on the board
row 2: U3.34 (GPIO22); also elsewhere on the board
row 3: U3.32 (GPIO21); also elsewhere on the board
row 4: U3.31 (GPIO20); also elsewhere on the board
row 5: U3.30 (GPIO19); also elsewhere on the board
row 6: U3.29 (GPIO18); also elsewhere on the board

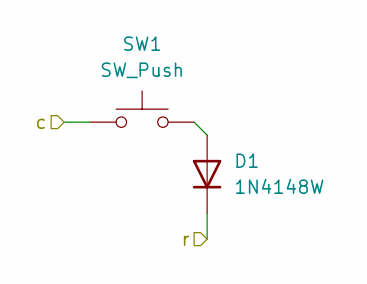
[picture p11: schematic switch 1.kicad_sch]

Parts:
D1: 1N4148W; D_SOD-123
SW1: SW_Push; Hotswap_MX_1.00u

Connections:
unnamed: D1.2 (A), SW1.2
column 1: SW1.1; also elsewhere on the board
row 1: D1.1 (K); also elsewhere on the board

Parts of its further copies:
D2, D3, D4, D5, D6, D7, D8, D9, D10, D11, D12, D13, D14, D15, D16, D17, D18, D19, D20, D21, D22, D23, D24, D25, D26, D27, D28, D30, D31, D32, D33, D36, D37, D38, D39, D40, D41, D42, D43, D44, D45, D46, D47, D49, D50, D51, D54, D55, D56, D57, D58, D59, D60, D61, D62, D63, D64, D66, D67, D68, D70, D71, D72, D73, D74, D75, D76, D77, D78, D79, D80, D81, D82, D83, D84, D89, D90, D91, D92, D93, D94, D95, D96: 1N4148W; D_SOD-123
SW2, SW3, SW4, SW5, SW6, SW7, SW8, SW9, SW10, SW11, SW12, SW13, SW14, SW15, SW16, SW17, SW18, SW19, SW20, SW21, SW22, SW23, SW24, SW25, SW26, SW27, SW28, SW30, SW31, SW32, SW33, SW36, SW37, SW38, SW39, SW40, SW41, SW42, SW43, SW44, SW45, SW46, SW47, SW49, SW50, SW51, SW54, SW55, SW56, SW57, SW58, SW59, SW60, SW61, SW62, SW63, SW64, SW66, SW67, SW68, SW70, SW71, SW72, SW73, SW74, SW75, SW76, SW77, SW78, SW79, SW80, SW81, SW82, SW83, SW84, SW89, SW90, SW91, SW92, SW93, SW94, SW95, SW96: SW_Push; Hotswap_MX_1.00u

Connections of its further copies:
unnamed: D2.2 (A), SW2.2
unnamed: D3.2 (A), SW3.2
unnamed: D4.2 (A), SW4.2
unnamed: D5.2 (A), SW5.2
unnamed: D6.2 (A), SW6.2
unnamed: D7.2 (A), SW7.2
unnamed: D8.2 (A), SW8.2
unnamed: D9.2 (A), SW9.2
unnamed: D10.2 (A), SW10.2
unnamed: D11.2 (A), SW11.2
unnamed: D12.2 (A), SW12.2
unnamed: D13.2 (A), SW13.2
unnamed: D14.2 (A), SW14.2
unnamed: D15.2 (A), SW15.2
unnamed: D16.2 (A), SW16.2
unnamed: D17.2 (A), SW17.2
unnamed: D18.2 (A), SW18.2
unnamed: D19.2 (A), SW19.2
unnamed: D20.2 (A), SW20.2
unnamed: D21.2 (A), SW21.2
unnamed: D22.2 (A), SW22.2
unnamed: D23.2 (A), SW23.2
unnamed: D24.2 (A), SW24.2
unnamed: D25.2 (A), SW25.2
unnamed: D26.2 (A), SW26.2
unnamed: D27.2 (A), SW27.2
unnamed: D28.2 (A), SW28.2
unnamed: D30.2 (A), SW30.2
unnamed: D31.2 (A), SW31.2
unnamed: D32.2 (A), SW32.2
unnamed: D33.2 (A), SW33.2
unnamed: D36.2 (A), SW36.2
unnamed: D37.2 (A), SW37.2
unnamed: D38.2 (A), SW38.2
unnamed: D39.2 (A), SW39.2
unnamed: D40.2 (A), SW40.2
unnamed: D41.2 (A), SW41.2
unnamed: D42.2 (A), SW42.2
unnamed: D43.2 (A), SW43.2
unnamed: D44.2 (A), SW44.2
unnamed: D45.2 (A), SW45.2
unnamed: D46.2 (A), SW46.2
unnamed: D47.2 (A), SW47.2
unnamed: D49.2 (A), SW49.2
unnamed: D50.2 (A), SW50.2
unnamed: D51.2 (A), SW51.2
unnamed: D54.2 (A), SW54.2
unnamed: D55.2 (A), SW55.2
unnamed: D56.2 (A), SW56.2
unnamed: D57.2 (A), SW57.2
unnamed: D58.2 (A), SW58.2
unnamed: D59.2 (A), SW59.2
unnamed: D60.2 (A), SW60.2
unnamed: D61.2 (A), SW61.2
unnamed: D62.2 (A), SW62.2
unnamed: D63.2 (A), SW63.2
unnamed: D64.2 (A), SW64.2
unnamed: D66.2 (A), SW66.2
unnamed: D67.2 (A), SW67.2
unnamed: D68.2 (A), SW68.2
unnamed: D70.2 (A), SW70.2
unnamed: D71.2 (A), SW71.2
unnamed: D72.2 (A), SW72.2
unnamed: D73.2 (A), SW73.2
unnamed: D74.2 (A), SW74.2
unnamed: D75.2 (A), SW75.2
unnamed: D76.2 (A), SW76.2
unnamed: D77.2 (A), SW77.2
unnamed: D78.2 (A), SW78.2
unnamed: D79.2 (A), SW79.2
unnamed: D80.2 (A), SW80.2
unnamed: D81.2 (A), SW81.2
unnamed: D82.2 (A), SW82.2
unnamed: D83.2 (A), SW83.2
unnamed: D84.2 (A), SW84.2
unnamed: D89.2 (A), SW89.2
unnamed: D90.2 (A), SW90.2
unnamed: D91.2 (A), SW91.2
unnamed: D92.2 (A), SW92.2
unnamed: D93.2 (A), SW93.2
unnamed: D94.2 (A), SW94.2
unnamed: D95.2 (A), SW95.2
unnamed: D96.2 (A), SW96.2
column 1: SW16.1; also elsewhere on the board
column 2: SW2.1, SW17.1, SW36.1, SW54.1, SW70.1; also elsewhere on the board
column 3: SW3.1, SW18.1, SW37.1, SW55.1, SW71.1; also elsewhere on the board
column 4: SW4.1, SW19.1, SW38.1, SW56.1, SW72.1; also elsewhere on the board
column 5: SW5.1, SW20.1, SW39.1, SW57.1, SW73.1; also elsewhere on the board
column 6: SW6.1, SW21.1, SW40.1, SW58.1, SW74.1; also elsewhere on the board
column 7: SW22.1, SW41.1, SW59.1, SW75.1; also elsewhere on the board
column 8: SW7.1, SW23.1, SW42.1, SW60.1, SW76.1; also elsewhere on the board
column 9: SW8.1, SW24.1, SW43.1, SW61.1, SW77.1; also elsewhere on the board
column 10: SW9.1, SW25.1, SW44.1, SW62.1, SW78.1, SW89.1; also elsewhere on the board
column 11: SW26.1, SW45.1, SW63.1, SW79.1, SW90.1; also elsewhere on the board
column 12: SW10.1, SW27.1, SW46.1, SW64.1, SW91.1; also elsewhere on the board
column 13: SW11.1, SW28.1, SW47.1, SW80.1, SW92.1; also elsewhere on the board
column 14: SW12.1, SW81.1, SW93.1; also elsewhere on the board
column 15: SW13.1, SW30.1, SW49.1, SW66.1, SW82.1, SW94.1; also elsewhere on the board
column 16: SW14.1, SW31.1, SW50.1, SW67.1, SW83.1, SW95.1; also elsewhere on the board
column 17: SW15.1, SW32.1, SW51.1, SW68.1, SW84.1, SW96.1; also elsewhere on the board
column 18: SW33.1; also elsewhere on the board
row 1: D2.1 (K), D3.1 (K), D4.1 (K), D5.1 (K), D6.1 (K), D7.1 (K), D8.1 (K), D9.1 (K), D10.1 (K), D11.1 (K), D12.1 (K), D13.1 (K), D14.1 (K), D15.1 (K); also elsewhere on the board
row 2: D16.1 (K), D17.1 (K), D18.1 (K), D19.1 (K), D20.1 (K), D21.1 (K), D22.1 (K), D23.1 (K), D24.1 (K), D25.1 (K), D26.1 (K), D27.1 (K), D28.1 (K), D30.1 (K), D31.1 (K), D32.1 (K), D33.1 (K); also elsewhere on the board
row 3: D36.1 (K), D37.1 (K), D38.1 (K), D39.1 (K), D40.1 (K), D41.1 (K), D42.1 (K), D43.1 (K), D44.1 (K), D45.1 (K), D46.1 (K), D47.1 (K), D49.1 (K), D50.1 (K), D51.1 (K); also elsewhere on the board
row 4: D54.1 (K), D55.1 (K), D56.1 (K), D57.1 (K), D58.1 (K), D59.1 (K), D60.1 (K), D61.1 (K), D62.1 (K), D63.1 (K), D64.1 (K), D66.1 (K), D67.1 (K), D68.1 (K); also elsewhere on the board
row 5: D70.1 (K), D71.1 (K), D72.1 (K), D73.1 (K), D74.1 (K), D75.1 (K), D76.1 (K), D77.1 (K), D78.1 (K), D79.1 (K), D80.1 (K), D81.1 (K), D82.1 (K), D83.1 (K), D84.1 (K); also elsewhere on the board
row 6: D89.1 (K), D90.1 (K), D91.1 (K), D92.1 (K), D93.1 (K), D94.1 (K), D95.1 (K), D96.1 (K); also elsewhere on the board

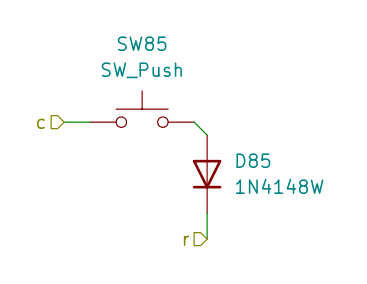
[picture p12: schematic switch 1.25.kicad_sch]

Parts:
D85: 1N4148W; D_SOD-123
SW85: SW_Push; Hotswap_MX_1.25u

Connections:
unnamed: D85.2 (A), SW85.2
column 1: SW85.1; also elsewhere on the board
row 6: D85.1 (K); also elsewhere on the board

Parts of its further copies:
D86, D87: 1N4148W; D_SOD-123
SW86, SW87: SW_Push; Hotswap_MX_1.25u

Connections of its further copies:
unnamed: D86.2 (A), SW86.2
unnamed: D87.2 (A), SW87.2
column 2: SW86.1; also elsewhere on the board
column 3: SW87.1; also elsewhere on the board
row 6: D86.1 (K), D87.1 (K); also elsewhere on the board

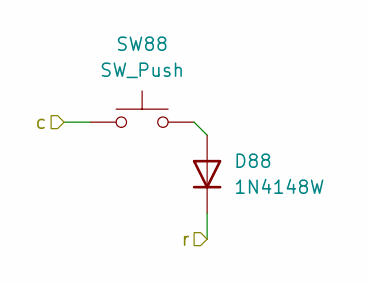
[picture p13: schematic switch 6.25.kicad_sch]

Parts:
D88: 1N4148W; D_SOD-123
SW88: SW_Push; Hotswap_MX_6.25u

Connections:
unnamed: D88.2 (A), SW88.2
column 6: SW88.1; also elsewhere on the board
row 6: D88.1 (K); also elsewhere on the board

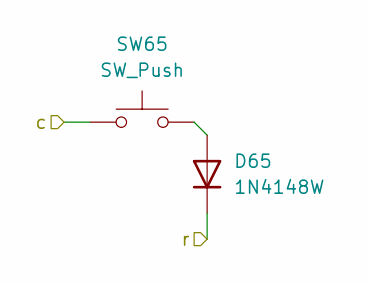
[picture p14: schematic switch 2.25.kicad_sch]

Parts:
D65: 1N4148W; D_SOD-123
SW65: SW_Push; Hotswap_MX_2.25u

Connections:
unnamed: D65.2 (A), SW65.2
column 13: SW65.1; also elsewhere on the board
row 4: D65.1 (K); also elsewhere on the board

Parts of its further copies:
D69: 1N4148W; D_SOD-123
SW69: SW_Push; Hotswap_MX_2.25u

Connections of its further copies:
unnamed: D69.2 (A), SW69.2
column 1: SW69.1; also elsewhere on the board
row 5: D69.1 (K); also elsewhere on the board

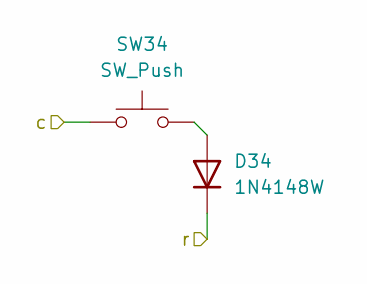
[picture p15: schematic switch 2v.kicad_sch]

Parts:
D34: 1N4148W; D_SOD-123
SW34: SW_Push; Hotswap_MX_2.00u_90deg

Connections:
unnamed: D34.2 (A), SW34.2
column 18: SW34.1; also elsewhere on the board
row 6: D34.1 (K); also elsewhere on the board

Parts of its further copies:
D52: 1N4148W; D_SOD-123
SW52: SW_Push; Hotswap_MX_2.00u_90deg

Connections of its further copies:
unnamed: D52.2 (A), SW52.2
column 18: SW52.1; also elsewhere on the board
row 3: D52.1 (K); also elsewhere on the board

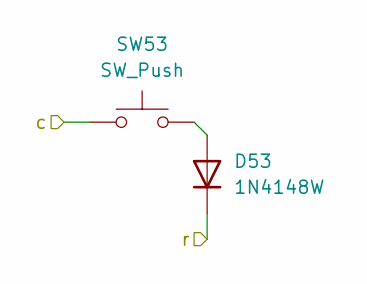
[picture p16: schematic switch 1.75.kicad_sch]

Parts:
D53: 1N4148W; D_SOD-123
SW53: SW_Push; Hotswap_MX_1.75u

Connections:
unnamed: D53.2 (A), SW53.2
column 1: SW53.1; also elsewhere on the board
row 4: D53.1 (K); also elsewhere on the board

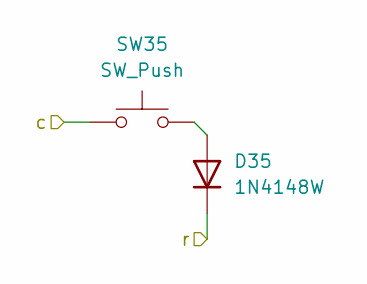
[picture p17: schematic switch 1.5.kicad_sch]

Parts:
D35: 1N4148W; D_SOD-123
SW35: SW_Push; Hotswap_MX_1.50u

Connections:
unnamed: D35.2 (A), SW35.2
column 1: SW35.1; also elsewhere on the board
row 3: D35.1 (K); also elsewhere on the board

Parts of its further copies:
D48: 1N4148W; D_SOD-123
SW48: SW_Push; Hotswap_MX_1.50u

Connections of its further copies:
unnamed: D48.2 (A), SW48.2
column 14: SW48.1; also elsewhere on the board
row 3: D48.1 (K); also elsewhere on the board

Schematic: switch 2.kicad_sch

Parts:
D29: 1N4148W; D_SOD-123
SW29: SW_Push; Hotswap_MX_2.00u

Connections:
unnamed: D29.2 (A), SW29.2
column 14: SW29.1; also elsewhere on the board
row 2: D29.1 (K); also elsewhere on the board

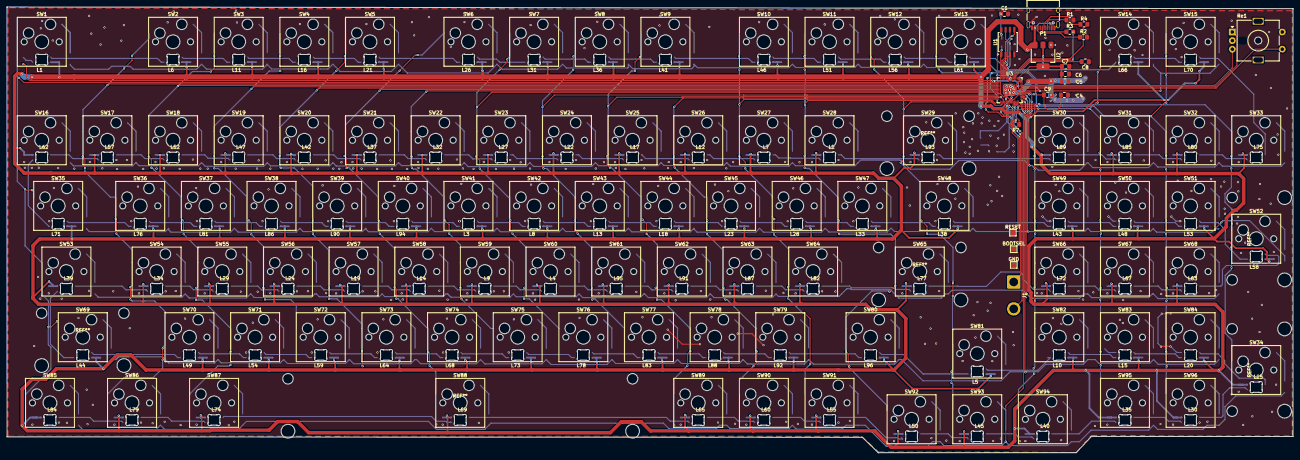
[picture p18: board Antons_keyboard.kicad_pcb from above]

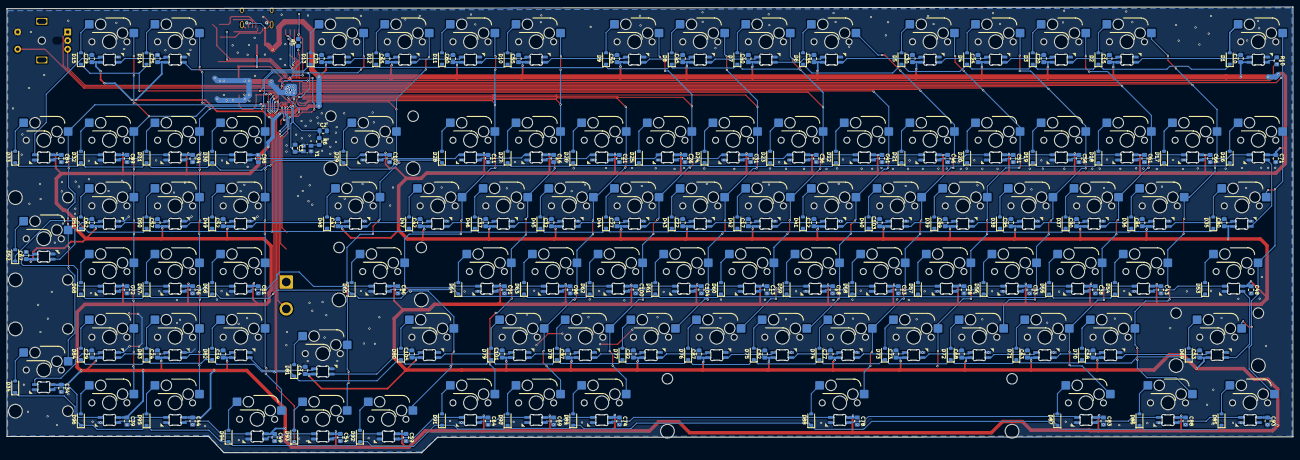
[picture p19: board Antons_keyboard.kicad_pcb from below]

Board: 2 copper layers, 373.2 x 129.3 mm, 411 parts (198 on the bottom side), 241 nets.

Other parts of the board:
BOOTSEL: TestPoint; TestPoint_Pad_1.5x1.5mm
GND: TestPoint; TestPoint_Pad_1.5x1.5mm
RESET: TestPoint; TestPoint_Pad_1.5x1.5mm

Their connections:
GND: GND.1 (1_1); also elsewhere on the board
unnamed 205: BOOTSEL.1 (1_1); also elsewhere on the board
unnamed 213: RESET.1 (1_1); also elsewhere on the board

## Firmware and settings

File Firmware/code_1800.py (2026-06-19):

# code.py — 1800 Compact Keyboard (96-key)
# Firmware: KMK (CircuitPython)
# Matrix: 6 rows × 18 columns = 108 positions (12 unused/empty)
#
# Flash instructions:
#   1. Install CircuitPython on your MCU
#   2. Copy the KMK folder to CIRCUITPY/
#      (download from https://github.com/KMKfw/kmk_firmware)
#   3. Save this file as code.py on CIRCUITPY/
#
# ─────────────────────────────────────────────────────────────────

import board
from kmk.kmk_keyboard import KMKKeyboard
from kmk.keys import KC
from kmk.scanners import DiodeOrientation
from kmk.modules.layers import Layers
from kmk.extensions.media_keys import MediaKeys

keyboard = KMKKeyboard()

keyboard.modules.append(Layers())
keyboard.extensions.append(MediaKeys())

# ── Pin mapping ───────────────────────────────────────────────────
# Update these to match your MCU and wiring.
# Run `import board; print(dir(board))` to list available pins.

keyboard.col_pins = (
    board.D0,  board.D1,  board.D2,  board.D3,
    board.D4,  board.D5,  board.D6,  board.D7,
    board.D8,  board.D9,  board.D10, board.D11,
    board.D12, board.D13, board.D14, board.D15,
    board.D16, board.D17,
)  # 18 columns

keyboard.row_pins = (
    board.A0,  # Row 1 — Function row
    board.A1,  # Row 2 — Number row
    board.A2,  # Row 3 — QWERTY row
    board.A3,  # Row 4 — Home row
    board.A4,  # Row 5 — Bottom row
    board.A5,  # Row 6 — Space row
)  # 6 rows

keyboard.diode_orientation = DiodeOrientation.COL2ROW

# ── Keymap ────────────────────────────────────────────────────────
# 96-key 1800 compact layout — 6 rows × 18 columns.
# KC.TRNS marks unused matrix positions (no switch).
#
# Physical layout (standard 1800 compact):
#
# Row 1 — Function row (16 keys + 2 nav)
# ┌────┬────┬────┬────┬────┬────┬────┬────┬────┬────┬────┬────┬────┬────────┬────┬────┬────┬────┐
# │ESC │ F1 │ F2 │ F3 │ F4 │ F5 │ F6 │ F7 │ F8 │ F9 │F10 │F11 │F12 │  DEL   │PSCR│SCRL│PAUS│    │
# └────┴────┴────┴────┴────┴────┴────┴────┴────┴────┴────┴────┴────┴────────┴────┴────┴────┴────┘
#
# Row 2 — Number row (14 keys + numpad top)
# ┌────┬────┬────┬────┬────┬────┬────┬────┬────┬────┬────┬────┬────┬────────┬────┬────┬────┬────┐
# │ `  │ 1  │ 2  │ 3  │ 4  │ 5  │ 6  │ 7  │ 8  │ 9  │ 0  │ -  │ =  │ BSPC   │INS │HOME│PGUP│NLCK│
# └────┴────┴────┴────┴────┴────┴────┴────┴────┴────┴────┴────┴────┴────────┴────┴────┴────┴────┘
#
# Row 3 — QWERTY row
# ┌──────┬────┬────┬────┬────┬────┬────┬────┬────┬────┬────┬────┬────┬──────┬────┬────┬────┬────┐
# │ TAB  │ Q  │ W  │ E  │ R  │ T  │ Y  │ U  │ I  │ O  │ P  │ [  │ ]  │  \   │DEL │END │PGDN│ /  │
# └──────┴────┴────┴────┴────┴────┴────┴────┴────┴────┴────┴────┴────┴──────┴────┴────┴────┴────┘
#
# Row 4 — Home row
# ┌───────┬────┬────┬────┬────┬────┬────┬────┬────┬────┬────┬────┬───────────┬────┬────┬────┬────┐
# │ CAPS  │ A  │ S  │ D  │ F  │ G  │ H  │ J  │ K  │ L  │ ;  │ '  │   ENTER   │ 7  │ 8  │ 9  │ -  │
# └───────┴────┴────┴────┴────┴────┴────┴────┴────┴────┴────┴────┴───────────┴────┴────┴────┴────┘
#
# Row 5 — Shift row
# ┌─────────┬────┬────┬────┬────┬────┬────┬────┬────┬────┬────┬─────────┬────┬────┬────┬────┬────┐
# │  LSFT   │ Z  │ X  │ C  │ V  │ B  │ N  │ M  │ ,  │ .  │ /  │  RSFT   │ ↑  │ 1  │ 2  │ 3  │ +  │
# └─────────┴────┴────┴────┴────┴────┴────┴────┴────┴────┴────┴─────────┴────┴────┴────┴────┴────┘
#
# Row 6 — Bottom row
# ┌─────┬─────┬─────┬──────────────────────────────┬─────┬─────┬─────┬────┬────┬────┬────┬────┐
# │LCTL │LGUI │LALT │            SPACE              │RALT │RGUI │RCTL │ ←  │ ↓  │ →  │ 0  │ENT │
# └─────┴─────┴─────┴──────────────────────────────┴─────┴─────┴─────┴────┴────┴────┴────┴────┘

keyboard.keymap = [
    [
        # Row 1 — Function row (18 keys, last position unused)
        KC.ESC,  KC.F1,   KC.F2,   KC.F3,   KC.F4,   KC.F5,   KC.F6,   KC.F7,
        KC.F8,   KC.F9,   KC.F10,  KC.F11,  KC.F12,  KC.DEL,  KC.PSCR, KC.SCRL,
        KC.PAUS, KC.TRNS,

        # Row 2 — Number row + right cluster top + numlock
        KC.GRV,  KC.N1,   KC.N2,   KC.N3,   KC.N4,   KC.N5,   KC.N6,   KC.N7,
        KC.N8,   KC.N9,   KC.N0,   KC.MINS, KC.EQL,  KC.BSPC, KC.INS,  KC.HOME,
        KC.PGUP, KC.NLCK,

        # Row 3 — QWERTY row + right cluster mid + numpad top
        KC.TAB,  KC.Q,    KC.W,    KC.E,    KC.R,    KC.T,    KC.Y,    KC.U,
        KC.I,    KC.O,    KC.P,    KC.LBRC, KC.RBRC, KC.BSLS, KC.DEL,  KC.END,
        KC.PGDN, KC.PSLS,

        # Row 4 — Home row + numpad middle
        KC.CAPS, KC.A,    KC.S,    KC.D,    KC.F,    KC.G,    KC.H,    KC.J,
        KC.K,    KC.L,    KC.SCLN, KC.QUOT, KC.ENT,  KC.TRNS, KC.P7,   KC.P8,
        KC.P9,   KC.PMNS,

        # Row 5 — Shift row + arrows + numpad bottom
        KC.LSFT, KC.Z,    KC.X,    KC.C,    KC.V,    KC.B,    KC.N,    KC.M,
        KC.COMM, KC.DOT,  KC.SLSH, KC.RSFT, KC.UP,   KC.TRNS, KC.P1,   KC.P2,
        KC.P3,   KC.PPLS,

        # Row 6 — Bottom row + arrows + numpad 0 + numpad enter
        KC.LCTL, KC.LGUI, KC.LALT, KC.SPC,  KC.TRNS, KC.TRNS, KC.TRNS, KC.RALT,
        KC.RGUI, KC.RCTL, KC.LEFT, KC.DOWN, KC.RGHT, KC.TRNS, KC.P0,   KC.TRNS,
        KC.PDOT, KC.PENT,
    ]
]

# ── Start! ────────────────────────────────────────────────────────
if __name__ == '__main__':
    keyboard.go()

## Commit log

2026-06-19 File update
    [Antons_Keyboard_Macondo-bom .csv, Antons_keyboard_Macondo.kicad_pcb, Antons_keyboard_Macondo.kicad_sch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]
2026-09-12 Update README with project information and BOM
    Added project details, images, and BOM to README.
2026-09-12 I added journal.md
    [BOM_Keyboard.csv]
2026-09-13 I changed some files names
    [Antons_keyboard.f3d, Antons_keyboard.kicad_pcb, Antons_keyboard.kicad_sch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]
2026-09-13 I added the files I had forgotten to add
    [switch 1.25.kicad_sch, switch 1.5.kicad_sch, switch 1.75.kicad_sch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]
